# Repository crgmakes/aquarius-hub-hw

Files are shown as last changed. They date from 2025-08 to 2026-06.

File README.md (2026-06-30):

# Aquarius Hub Hardware

All the source files for the hub hardware.

# Software 

You will need [KiCad](https://kicad.org) to view and edit this design. Click [here](https://www.kicad.org/download/) to download.

You will also need all the associated libraries and models to drive the design if you want to make changes or view the 3D rendering:

https://github.com/crgmakes/kicad-library.git

Kicad MUST be configured properly to use all the files in this repo. Once you have Kicad installed, under Preferences->Configure Paths..., make the following entries:

1 - KICAD_USER_DIR -> set to the root location of where you placed the above repository.
2 - KICAD_USER_LIBRARY = ${KICAD_USER_DIR}/Library
3 - KICAD_USER_MODEL_DIR = ${KICAD_USER_LIBRARY}/models
4 - KICAD_USER_TEMPLATE_DIR	= ${KICAD_USER_LIBRARY}/templates	

Kicad will operate mostly normally if these are not set properly. You will notice an issue when you view the PCB in 3D mode.

***NOTE***: after makeing a release build in git, if your rendered 3D images are missing components, ensure the path to EVERY component model is set to ${KICAD_USER_MODEL_DIR}/<model name>.

Kicad sometimes replaces the variable with an expansion and that FAILS during the build process because the expanded variable is local and does not match the build environment.

---

THE DESIGN IS PROVIDED "AS IS" AND THE AUTHOR DISCLAIMS ALL WARRANTIES WITH REGARD TO THIS DESIGN INCLUDING ALL IMPLIED WARRANTIES OF MERCHANTABILITY AND FITNESS. IN NO EVENT SHALL THE AUTHOR BE LIABLE FOR ANY SPECIAL, DIRECT, INDIRECT, OR CONSEQUENTIAL DAMAGES OR ANY DAMAGES WHATSOEVER RESULTING FROM LOSS OF USE, DATA OR PROFITS, WHETHER IN AN ACTION OF CONTRACT, NEGLIGENCE OR OTHER TORTIOUS ACTION, ARISING OUT OF OR IN CONNECTION WITH THE USE OR PERFORMANCE OF THIS DESIGN.

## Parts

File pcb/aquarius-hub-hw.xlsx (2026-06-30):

Designator | Type | Value | Footprint | Populate | CPN | Manufacturer 1 | MPN 1 | Digikey | LCSC | Mouser
C1,C4,C5,C6,C7,C9 |  | 0.1uF | CRGM Passive:C_0603_1608Metric |  |  | Samsung | CL10B104KO8NNNC | 1276-1005-2-ND | C66501 | 187-CL10B104KO8NNNC
C2,C11,C12,C13 |  | 10uF | CRGM Passive:C_0603_1608Metric |  |  | Samsung | CL10A106MO8NQNC | 1276-1870-2-ND | C92487 | 187-CL10A106MO8NQNC
C3,C10,C14 |  | 1uF | CRGM Passive:C_0603_1608Metric |  |  | HRE | CL10B105KO8NNNC | 1276-1019-2-ND | C6119849 | 187-CL10B105KO8NNNC
C8 |  | 100uF | CRGM Passive:C_1206_3216Metric |  |  | Samsung | CL31A107MQHNNNE | 1276-1782-2-ND | C15008 | 187-CL31A107MQHNNNE
C17 |  | 220uF | CRGM Passive:CP_Elec_6.3x5.4 |  |  | ROQANG | RVT1A221M0605 | 3372-UE227M010HEHTATR-ND | C72494 | 80-EDH227M6R3A9GAA
D1 |  | WS2812B-2020 | LED_SMD:LED_WS2812B-2020_PLCC4_2.0x2.0mm |  |  | World Semi | WS2812C-2020-V1 |  | C5349954
D2 |  | D_Schottky | CRGM Passive:D_SOD-523 |  |  | Shikues | MSK4010 | 1727-5834-2-ND | C345958 | 771-PMEG3010EB115
D3,D20 |  | PESD5V5C1BL | CRGM Passive:DFN1006-2 |  |  | Nexperia | PESD5V5C1BLYL | 1727-PESD5V5C1BLYLTR-ND | C2827636 | 771-PESD5V5C1BLYL
D4,D5,D6,D7,D8,D9,D10,D11,D12,D13,D14,D15,D16,D17,D18,D19,D21,D22,D25,D26,D27,D28 |  | PESD3V3S1BL | CRGM Passive:DFN1006-2 |  |  | FUXINSEMI | LESD8D3.3CAT5G | 1727-PESD3V3S1BLYLTR-ND | C5563754 | 621-DESD3V3S1BL-7B
D23,D24 |  | Orange | CRGM Passive:LED_0603_1608Metric |  |  | XINGLIGHT | XL-1608UOC-06 | 5962-XL-1608UOC-06TR-ND | C965800 | 859-LTST-C190KFKT
J1 |  | ~ | CRGM Connector:XF2M-1415-1A |  |  | Omron | XF2M-1415-1A | OR755TR-ND | C397114 | 653-XF2M-1415-1A
J2 |  | USB_C_USB2.0_16P | CRGM Connector:GCT_USB4105-GF-A |  |  | GTC | USB4105-GF-A-060 | 2073-USB4105-GF-A-060TR-ND | C165948 | 640-USB4105-GF-A-060
J3,J11,J14 |  | ~ | CRGM Connector:JST_SH_BM03B-SRSS-TB_1x03-1MP_P1.00mm_Vertical |  |  | JST | BM03B-SRSS-TB | 455-BM03B-SRSS-TBTR-ND | C2904985 | 306-BM03BSRSSTBTLFSN
J4,J5,J7 |  | ~ | CRGM Connector:JST_SH_BM06B-SRSS-TB_1x06-1MP_P1.00mm_Vertical |  |  | JST | BM06B-SRSS-TBT(LF)(SN) | 455-BM06B-SRSS-TBTR-ND | C2845374 | 306-BM06BSRSSTBTLFSN
J6,J10 |  | ~ | CRGM Connector:JST_SH_BM08B-SRSS-TB_1x08-1MP_P1.00mm_Vertical |  |  | JST | BM08B-SRSS-TB(LF)(SN) | 455-BM08B-SRSS-TBTR-ND | C2845376 | 306-BM08BSRSSTBLFSN
J8,J9,J12 |  | ~ | CRGM Connector:JST_SH_BM04B-SRSS-TB_1x04-1MP_P1.00mm_Vertical |  |  | JST | BM04B-SRSS-TBT(LF)(SN) | 455-BM04B-SRSS-TBTR-ND | C2919601 | 306-BM04BSRSSTBTLFSN
LS1 |  | FUET-5020 | CRG Makes:FUET-5025 |  |  | Fuet | FUET-5020 | 102-CMT-0502-75-SMT-TR-ND | C391029 | 490-CMT-0502-75SMTTR
Q1 |  | MMBT2222A | CRGM Passive:SOT-523 |  |  | Diodes Incorporated | MMBT2222AT-7-F | MMBT2222AT-FDITR-ND | C151009 | 621-MMBT2222AT-F
R1,R2,R15 |  | 4.7K | CRGM Passive:R_0603_1608Metric |  |  | FOJAN | FRC0603J472 TS | CR0603-JW-472ELFTR-ND | C2907166 | 652-CR0603-JW-472ELF
R3,R4,R5,R6,R7,R8,R9,R13,R14 |  | 10K | CRGM Passive:R_0603_1608Metric |  |  | FOJAN | FRC0603J103TS | CR0603-JW-103ELFTR-ND | C2930027 | 652-CR0603-JW-103ELF
R10,R11 |  | 5.1K | CRGM Passive:R_0603_1608Metric |  |  | FOJAN | FRC0603J512 TS | 118-CR0603-JW-512ELFTR-ND | C2907114 | 652-CR0603JW-512ELF
R12,R16 |  | 1K | CRGM Passive:R_0603_1608Metric |  |  | FOJAN | FRC0603J102 TS | CR0603-JW-102ELFTR-ND | C2907113 | 652-CR0603-JW-102ELF
SW1,SW2 |  | SKRPABE010 | CRGM Switches:SMD-4P-4.2x3.2mm |  |  | ALPS Electric | SKRPABE010 | 4809-SKRPABE010TR-ND | C115360 | 688-SKRPAB
U1 |  | ESP32-S3-WROOM-1-N16R2 | CRG Makes:ESP32-S3-WROOM-1-N16R2 |  |  | Espressif | ESP32-S3-WROOM-1-N16R2 | 5407-ESP32-S3-WROOM-1-N16R2-ND | C2913205 | 356-ESP32-S3WRM1N16R2
U2 |  | LM66200DRLR | CRGM Power:SOTFL50P160X60-8N |  |  | Texas Instruments | LM66200DRLR | 296-LM66200DRLRTR-ND | C3235556 | 595-LM66200DRLR
U3 |  | USBLC6-2P6 | CRGM Passive:SOT-666 |  |  | TECH PUBLIC | USBLC6-2P6 | 497-5026-2-ND | C2827693 | 511-USBLC6-2P6
U4 |  | MCP23017T-E/ML | CRG Makes:QFN-28-1EP_6x6mm_P0.65mm_EP4.25x4.25mm |  |  | Microchip Tech | MCP23017T-E/ML | MCP23017-E/ML-ND | C629439 | 579-MCP23017-E/ML
U7 |  | AZ1084-3.3 | CRGM Power:TO-252-2 |  |  | Diodes Incorporated | AZ1084CD-3.3TRG1 | AZ1084CD-3.3TRG1DITR-ND | C151391 | 621-AZ1084CD-3.3TRG1

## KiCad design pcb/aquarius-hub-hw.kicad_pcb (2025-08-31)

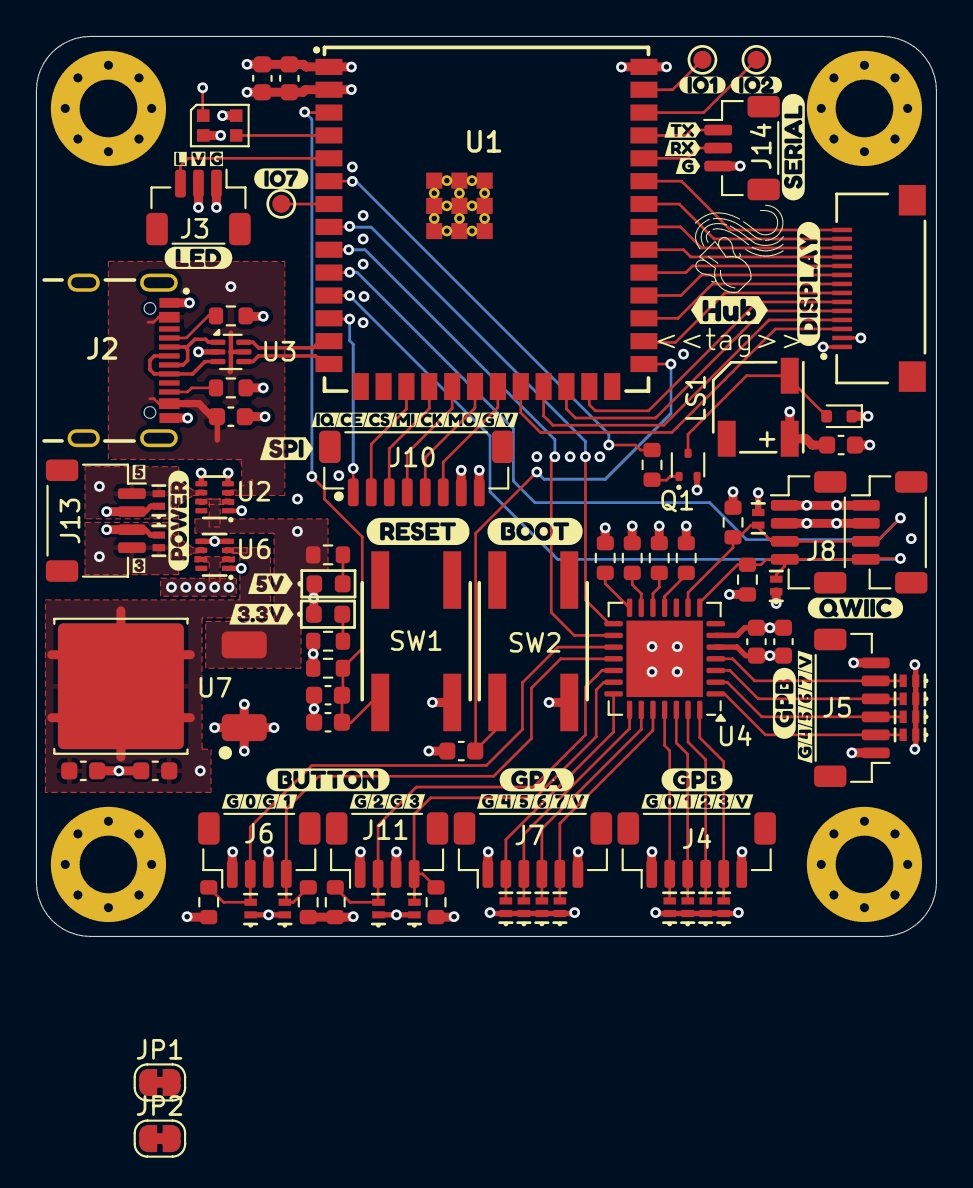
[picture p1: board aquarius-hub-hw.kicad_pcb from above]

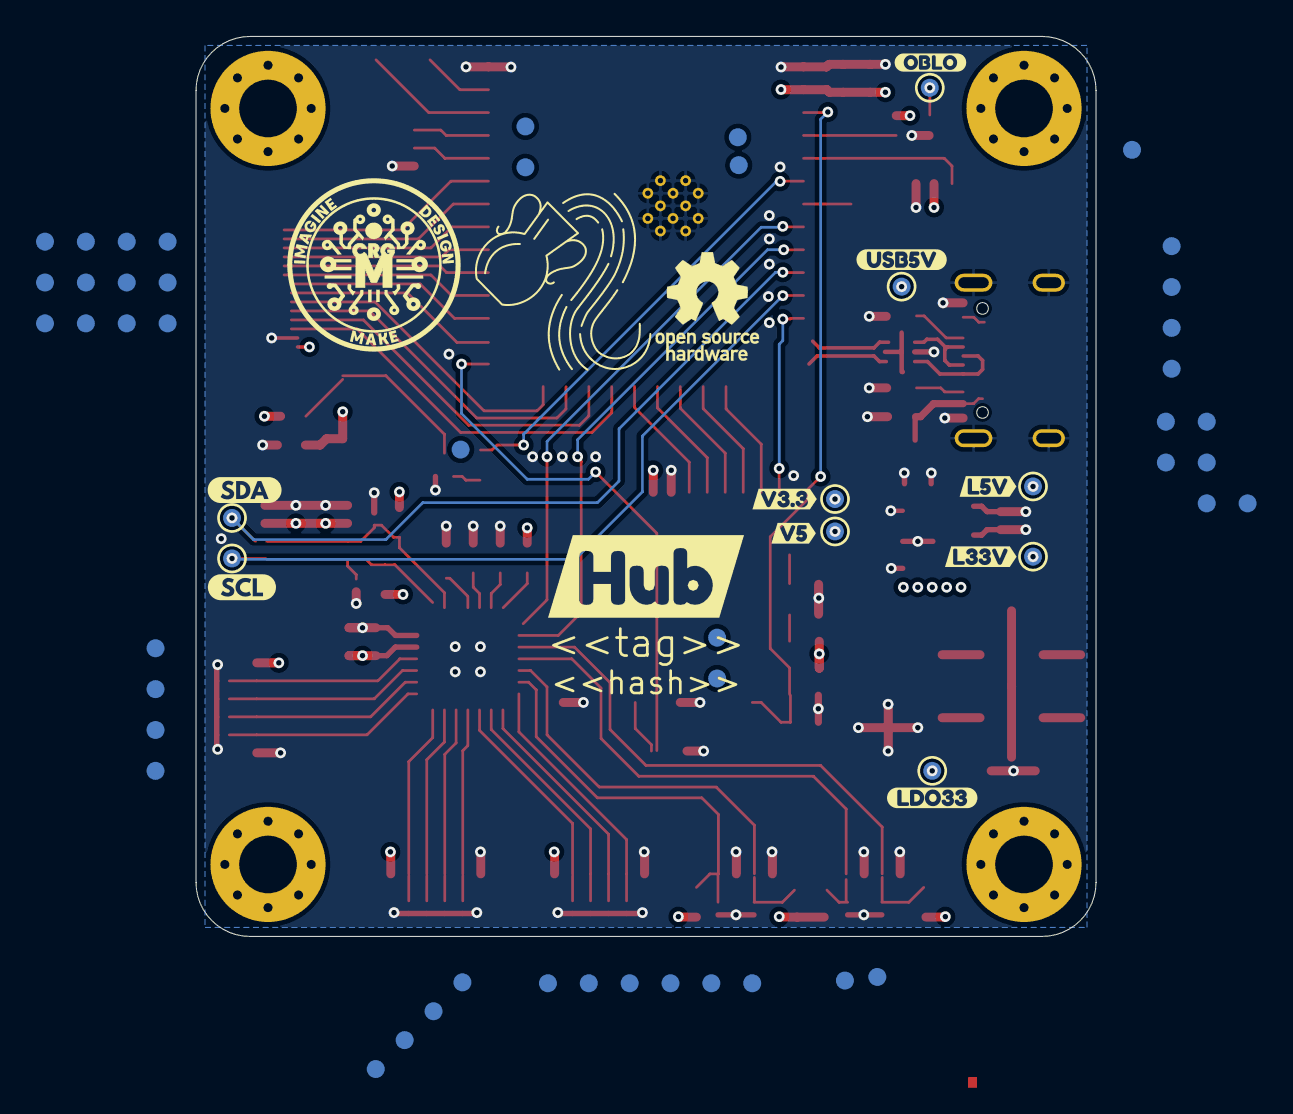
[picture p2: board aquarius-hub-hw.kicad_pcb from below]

Board: 4 copper layers, 50.0 x 50.0 mm, 212 parts (68 on the bottom side), 72 nets.

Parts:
C1, C4, C5, C6, C9: 0.1uF; C_0603_1608Metric
C2, C11, C12: 10uF; C_0603_1608Metric
C3, C10, C14: 1uF; C_0603_1608Metric
D1: WS2812B-2020; LED_WS2812B-2020_PLCC4_2.0x2.0mm
D2: D_Schottky; D_SOD-523
D4, D5, D6, D7, D8, D9, D10, D11, D12, D13, D14, D15, D16, D17, D18, D19, D21, D22, D25: PESD3V3S1BL; DFN1006-2
D20: PESD5V5C1BL; DFN1006-2
D23, D24: Orange; LED_0603_1608Metric
H1, H2, H3, H4: MountingHole_3.2mm_M3_Pad_Via
J1: XF2M-1415-1A
J2: USB_C_USB2.0_16P; GCT_USB4105-GF-A
J3, J14: BM03B-SRSS-TB; JST_SH_BM03B-SRSS-TB_1x03-1MP_P1.00mm_Vertical
J4, J5, J7: BM06B-SRSS-TB; JST_SH_BM06B-SRSS-TB_1x06-1MP_P1.00mm_Vertical
J6, J8, J9, J11: BM04B-SRSS-TB; JST_SH_BM04B-SRSS-TB_1x04-1MP_P1.00mm_Vertical
J10: BM08B-SRSS-TB; JST_SH_BM08B-SRSS-TB_1x08-1MP_P1.00mm_Vertical
J13: SM04B-SRSS-TB; JST_SH_SM04B-SRSS-TB_1x04-1MP_P1.00mm_Horizontal
JP1, JP2: SolderJumper-2_P1.3mm_Bridged_RoundedPad1.0x1.5mm
LOGO1: CRGM Logo 5mm
LOGO2: Aquarius Logo 10mm
LOGO3: OSHW-Logo_5.7x6mm_SilkScreen
LOGO4: Aquarius Logo 5mm
LS1: FUET-5025
Q1: MMBT2222A; SOT-523
R1, R2, R15: 4.7K; R_0603_1608Metric
R3, R4, R5, R6, R7, R8, R9, R13, R14: 10K; R_0603_1608Metric
R10, R11: 5.1K; R_0603_1608Metric
R12, R16: 1K; R_0603_1608Metric
SW1, SW2: EVQ-Q2B02W
TP1, TP2, TP3, TP4, TP5, TP6, TP7, TP8, TP9, TP10, TP11, TP12, TP13, TP14, TP15, TP16, TP17, TP18, TP19, TP20, TP21, TP22, TP23, TP24, TP25, TP26, TP27, TP28, TP29, TP30, TP31, TP32, TP33, TP34, TP35, TP36, TP37, TP38, TP39, TP40, TP41, TP42, TP43, TP44, TP45, TP46, TP47, TP48, TP49, TP50, TP51, TP52, TP53, TP54, TP55, TP56, TP57, TP58: TestPoint_Pad_D1.0mm
U1: ESP32-S3-WROOM-1-N8R2
U2, U6: LM66200DRLR; SOTFL50P160X60-8N
U3: USBLC6-2P6; SOT-666
U4: MCP23017T-E/ML; QFN-28-1EP_6x6mm_P0.65mm_EP4.25x4.25mm
U7: AZ1084-3.3; TO-252-2
kibuzzard-67B9F9C2: G***; kibuzzard-67B9F9C2
kibuzzard-67B9F9CD: G***; kibuzzard-67B9F9CD
kibuzzard-680D06A5: G***; kibuzzard-680D06A5
kibuzzard-680D069E: G***; kibuzzard-680D069E
kibuzzard-680D0262: G***; kibuzzard-680D0262
kibuzzard-683B54B0: G***; kibuzzard-683B54B0
kibuzzard-683B594D: G***; kibuzzard-683B594D
kibuzzard-683B5370: G***; kibuzzard-683B5370
kibuzzard-683B5376: G***; kibuzzard-683B5376
kibuzzard-683C500B: G***; kibuzzard-683C500B
kibuzzard-683C5017: G***; kibuzzard-683C5017
kibuzzard-689E525E: G***; kibuzzard-689E525E
kibuzzard-689E5275: G***; kibuzzard-689E5275
kibuzzard-6812E3A0: G***; kibuzzard-6812E3A0
kibuzzard-6812E3AD: G***; kibuzzard-6812E3AD
kibuzzard-6812E3BB: G***; kibuzzard-6812E3BB
kibuzzard-6812E3C5: G***; kibuzzard-6812E3C5
kibuzzard-6812E37E: G***; kibuzzard-6812E37E
kibuzzard-6812E420: G***; kibuzzard-6812E420
kibuzzard-68153CC4, kibuzzard-68153CC4#2, kibuzzard-68153CC4#3: G***; kibuzzard-68153CC4
kibuzzard-68153CC9: G***; kibuzzard-68153CC9
kibuzzard-68153CCE: G***; kibuzzard-68153CCE
kibuzzard-68153CDD: G***; kibuzzard-68153CDD
kibuzzard-68153CE4: G***; kibuzzard-68153CE4
kibuzzard-68153CEB: G***; kibuzzard-68153CEB
kibuzzard-68153CEF: G***; kibuzzard-68153CEF
kibuzzard-68194F3F: G***; kibuzzard-68194F3F
kibuzzard-68194F50: G***; kibuzzard-68194F50
kibuzzard-68366CAF: G***; kibuzzard-68366CAF
kibuzzard-68574A7C: G***; kibuzzard-68574A7C
kibuzzard-68574A8F: G***; kibuzzard-68574A8F
kibuzzard-68574A9F: G***; kibuzzard-68574A9F
kibuzzard-68574AC2: G***; kibuzzard-68574AC2
kibuzzard-68574AD3: G***; kibuzzard-68574AD3
kibuzzard-68574B95: G***; kibuzzard-68574B95
kibuzzard-68574D7F: G***; kibuzzard-68574D7F
kibuzzard-68574D8A: G***; kibuzzard-68574D8A
kibuzzard-68574D75: G***; kibuzzard-68574D75
kibuzzard-68574D94: G***; kibuzzard-68574D94
kibuzzard-681420CD: G***; kibuzzard-681420CD
kibuzzard-681420D1: G***; kibuzzard-681420D1
kibuzzard-681420D5: G***; kibuzzard-681420D5
kibuzzard-681420DA, kibuzzard-681420DA#2: G***; kibuzzard-681420DA
kibuzzard-681420E9: G***; kibuzzard-681420E9
kibuzzard-681420F3: G***; kibuzzard-681420F3
kibuzzard-681421A1: G***; kibuzzard-681421A1
kibuzzard-681421A9: G***; kibuzzard-681421A9
kibuzzard-683921F2: G***; kibuzzard-683921F2
kibuzzard-6810346D: G***; kibuzzard-6810346D
kibuzzard-6810349E: G***; kibuzzard-6810349E
kibuzzard-6814204F, kibuzzard-6814204F#2: G***; kibuzzard-6814204F
kibuzzard-6814212B: G***; kibuzzard-6814212B
kibuzzard-6815408B: G***; kibuzzard-6815408B
kibuzzard-6857318D: G***; kibuzzard-6857318D
kibuzzard-68142030, kibuzzard-68142030#2: G***; kibuzzard-68142030
kibuzzard-68142039, kibuzzard-68142039#2: G***; kibuzzard-68142039
kibuzzard-68142043, kibuzzard-68142043#2: G***; kibuzzard-68142043
kibuzzard-68142110: G***; kibuzzard-68142110
kibuzzard-68142199: G***; kibuzzard-68142199
kibuzzard-68154095, kibuzzard-68154095#2, kibuzzard-68154095#3: G***; kibuzzard-68154095
kibuzzard-68392226: G***; kibuzzard-68392226

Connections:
+3.3V: C1.1, C2.1, C9.1, C10.1, C14.1, D1.4 (VDD), D2.1 (K), J1.1, J3.2, J4.6, J5.6, J7.6, J8.2, J9.2, J10.8, LS1.2 (+), R1.1, R2.1, R3.1, R4.1, R5.1, R9.1, R13.1, R14.1, R16.1, TP8.1, U1.2 (3V3), U4.5 (VDD), U6.2 (VOUT1), U6.7 (VOUT2)
+5V: R15.1, TP12.1, U2.2 (VOUT1), U2.7 (VOUT2), U7.3 (VI)
/Interfaces/BUZZ_GND: D2.2 (A), LS1.3 (-), Q1.3 (C)
/PIO/A0: R6.1, U4.11 (A0)
/PIO/A1: R7.1, U4.12 (A1)
/PIO/A2: R8.1, U4.13 (A2)
/PIO/BTN0: D12.2 (K2), J6.2, R14.2, TP51.1, U4.17 (GPA0)
/PIO/BTN1: D13.2 (K2), J6.4, R13.2, TP52.1, U4.18 (GPA1)
/PIO/BTN2: D14.2 (K2), J11.2, R5.2, TP53.1, U4.19 (GPA2)
/PIO/BTN3: D15.2 (K2), J11.4, R4.2, TP54.1, U4.20 (GPA3)
/PIO/GPA4: D16.2 (K2), J7.2, TP55.1, U4.21 (GPA4)
/PIO/GPA5: D17.2 (K2), J7.3, TP56.1, U4.22 (GPA5)
/PIO/GPA6: D18.2 (K2), J7.4, TP57.1, U4.23 (GPA6)
/PIO/GPA7: D19.2 (K2), J7.5, TP58.1, U4.24 (GPA7)
/PIO/GPB0: D4.2 (K2), J4.2, TP43.1, U4.25 (GPB0)
/PIO/GPB1: D5.2 (K2), J4.3, TP44.1, U4.26 (GPB1)
/PIO/GPB2: D6.2 (K2), J4.4, TP45.1, U4.27 (GPB2)
/PIO/GPB3: D7.2 (K2), J4.5, TP46.1, U4.28 (GPB3)
/PIO/GPB4: D8.2 (K2), J5.2, TP47.1, U4.1 (GPB4)
/PIO/GPB5: D9.2 (K2), J5.3, TP48.1, U4.2 (GPB5)
/PIO/GPB6: D10.2 (K2), J5.4, TP49.1, U4.3 (GPB6)
/PIO/GPB7: D11.2 (K2), J5.5, TP50.1, U4.4 (GPB7)
/PIO/PIO_RESET: R9.2, U4.14 (~RESET)
/Power/CC1: J2.A5 (CC1), R11.1
/Power/CC2: J2.B5 (CC2), R10.1
/Power/V3.3LED: D24.2 (A), R16.2
/Power/V5LED: D23.2 (A), R15.2
BOOT: C5.1, SW2.B1 (B), TP41.1, U1.27 (IO0)
BUZZER: R12.1, TP42.1, U1.6 (IO6)
D_N: TP25.1, U1.13 (USB_D-), U3.6 (I/O1)
D_P: TP26.1, U1.14 (USB_D+), U3.4 (I/O2)
EN: C3.1, C4.1, R3.2, SW1.B1 (B), TP40.1, U1.3 (EN)
GND: C1.2, C2.2, C3.2, C4.2, C5.2, C6.2, C9.2, C10.2, C11.2, C12.2, C14.2, D1.2 (VSS), D4.1 (K1), D5.1 (K1), D6.1 (K1), D7.1 (K1), D8.1 (K1), D9.1 (K1), D10.1 (K1), D11.1 (K1), D12.1 (K1), D13.1 (K1), D14.1 (K1), D15.1 (K1), D16.1 (K1), D17.1 (K1), D18.1 (K1), D19.1 (K1), D20.1 (K1), D21.1 (K1), D22.1 (K1), D25.1 (K1), J1.2, J2.A1B12 (GND), J2.B1A12 (GND), J2.S1 (SHIELD), J3.1, J4.1, J5.1, J6.1, J6.3, J7.1, J8.1, J9.1, J10.7, J11.1, J11.3, J13.2 (GND), J13.3 (GND), J14.3, JP1.1 (A), JP2.1 (A), Q1.2 (E), R6.2, R7.2, R8.2, R10.2, R11.2, SW1.A1 (A), SW2.A1 (A), U1.1 (GND), U1.40 (GND), U1.41 (GND), U2.1 (GND1), U2.4 (~ON), U2.5 (GND2), U3.2 (GND), U4.6 (VSS), U4.29 (EP), U6.1 (GND1), U6.4 (~ON), U6.5 (GND2), U7.1 (GND)
I2C_SCL: D21.2 (K2), J8.4, J9.4, R2.2, TP2.1, U1.11 (IO18), U4.8 (SCK)
I2C_SDA: D22.2 (K2), J8.3, J9.3, R1.2, TP1.1, U1.10 (IO17), U4.9 (SDA)
LCD_BL: J1.8, TP18.1, U1.29 (IO36)
LCD_CS: J1.3, TP13.1, U1.22 (IO14)
LCD_DC: J1.5, TP15.1, U1.24 (IO47)
LCD_RS: J1.4, TP14.1, U1.23 (IO21)
LCD_SCK: J1.7, TP17.1, U1.28 (IO35)
LCD_SDI: J1.6, TP16.1, U1.25 (IO48)
LCD_SDO: J1.9, TP19.1, U1.30 (IO37)
LDO_V33: C11.1, C12.1, TP9.1, U6.3 (VIN1), U7.2 (VO)
LEDS: J3.3, U1.5 (IO5)
LINE_5V: D20.2 (K2), J13.1 (V5), TP10.1, U2.6 (VIN2)
LINE_V33: D25.2 (K2), J13.4 (V3.3), TP11.1, U6.6 (VIN2)
unnamed: D23.1 (K), JP1.2 (B)
unnamed: D24.1 (K), JP2.2 (B)
unnamed: Q1.1 (B), R12.2
unnamed: TP5.1, U1.39 (IO1)
unnamed: TP6.1, U1.38 (IO2)
unnamed: TP7.1, U1.7 (IO7)
OBL: D1.3 (DIN), TP39.1, U1.4 (IO4)
OBL_OUT: D1.1 (DOUT), TP3.1
PIO_INTA: TP37.1, U1.8 (IO15), U4.15 (INTB)
PIO_INTB: TP38.1, U1.9 (IO16), U4.16 (INTA)
RX: J14.2, TP30.1, U1.36 (RXD0)
SD_CS: J1.14, TP24.1, U1.35 (IO42)
SPI_CE0: J10.2, TP32.1, U1.17 (IO9)
SPI_CLK: J10.5, TP35.1, U1.20 (IO12)
SPI_CS0: J10.3, TP33.1, U1.18 (IO10)
SPI_IRQ0: J10.1, TP31.1, U1.12 (IO8)
SPI_MISO: J10.4, TP34.1, U1.19 (IO11)
SPI_MOSI: J10.6, TP36.1, U1.21 (IO13)
TX: J14.1, TP29.1, U1.37 (TXD0)
T_INT: J1.13, TP23.1, U1.34 (IO41)
T_RESET: J1.11, TP21.1, U1.32 (IO39)
T_SCL: J1.10, TP20.1, U1.31 (IO38)
T_SDA: J1.12, TP22.1, U1.33 (IO40)
USB_5V: C6.1, J2.A4B9 (VBUS), J2.B4A9 (VBUS), TP4.1, U2.3 (VIN1), U3.5 (VBUS)
USB_D_N: J2.A7 (D-), J2.B7 (D-), TP27.1, U3.1 (I/O1)
USB_D_P: J2.A6 (D+), J2.B6 (D+), TP28.1, U3.3 (I/O2)

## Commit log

2025-04-29 Major updates to IO and board size
    some issue with display of properties in schematic view.
    [Node copy.kicad_pcb, Node.kicad_pcb, io.kicad_sch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]
2025-04-30 Added buzzer
    [Node.kicad_pcb, mcu.kicad_sch, peripherals.kicad_sch]
2025-05-01 Changed SPI to 8 pin connector
    [Node.kicad_pcb, mcu.kicad_sch, peripherals.kicad_sch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]
2025-05-02 Added additional labels; minor clean up.
    [Node.kicad_pcb, peripherals.kicad_sch, pio.kicad_sch]
2025-05-05 added open hw; changed test points; added pulls on buttons
    change buttons to be 2 connectors with pull ups.
    [Node.kicad_pcb, mcu.kicad_sch, pio.kicad_sch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]
2025-05-05 added 1x2 panel
    [aq-hw-panel-sample.kicad_pcb, node-panel-1x2.kicad_pcb]
2025-05-08 Change panel to be 1x1
    Changed connectors be vertical rather than horizontal.
    Updated TVS diodes to DFN1006 rather than SMF
    [Node.kicad_pcb, Node.kicad_sch, mcu.kicad_sch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]
2025-06-01 Major overhaul of IO
    Added GPIO module
    Added SPI interface
    Added serial interface
    Added power selection
    Added power LEDs
    Changed v3.3 LDO
    [Node copy.kicad_pcb, Node.kicad_pcb, Node.kicad_sch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]
2025-06-01 Updated raytracing images on main page
    [Node.kicad_pcb, aq-hw-panel-sample.kicad_pcb]
2025-06-02 Fixed MPN mismatches and other fields
    [Node.kicad_pcb, mcu.kicad_sch, peripherals.kicad_sch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]
2025-06-02 Filleted PCB corners
    [Node.kicad_pcb]
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2025-06-03 Removed duplicative ESB on USB
    Updated descriptions for consistency
    [Node.kicad_pcb, mcu.kicad_sch, peripherals.kicad_sch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]
2025-06-07 Fixed cap values on reset button
    Fixed all part numbers and extended parameters.
    [Node.kicad_pcb, mcu.kicad_sch, peripherals.kicad_sch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]
2025-06-09 Rationalized attributes; excluded some footprints from BOM
    [Node.kicad_pcb, mcu.kicad_sch, power.kicad_sch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]
2025-06-21 Continued rationalizing parts
    [Node.kicad_pcb]
2025-06-21 Updated dimensions; updated mounting hole footprint
    [Node.kicad_pcb, mcu.kicad_sch]
2025-06-21 Adjusted part values
    Fixed LCSC footprints for connectors
    Moved EN 5% instead of 1%
    Moved I2C pull ups to 4.7K
    [Node.kicad_pcb, mcu.kicad_sch, peripherals.kicad_sch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]
2025-06-22 Cleaned up fab layer. Minor tweaks. Updated renders.
    [Node.kicad_pcb, peripherals.kicad_sch, pio.kicad_sch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]
2025-06-23 closed #3 and #1
    Fixed resistors and values
    Widened panel
    [Node.kicad_pcb, mcu.kicad_sch, peripherals.kicad_sch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]
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2025-06-24 updated ci script to include date of release and cash in schematic
    [mcu.kicad_sch, peripherals.kicad_sch, pio.kicad_sch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]
2025-06-24 added all schematics to tagging; remove unused files
    [io.kicad_sch, sensors.kicad_sch]
2025-06-26 Updated frame template
    [Node.kicad_pcb, mcu.kicad_sch, peripherals.kicad_sch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]
2025-06-26 Added PCB requirements to requirements sheet; adjusted user drawing layer a little
    [Node.kicad_pcb, requirements.kicad_sch]
2025-06-26 Fixed serial model; fixed CI script
    [Node.kicad_pcb]
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2025-06-27 Updated worksheet template and logo
    [Node.kicad_pcb, requirements.kicad_sch]
2025-06-27 fixed case of release file name.
2025-06-28 Fixed footprint for Buzzer, XFC, USB ESD, and Power Switcher
    [Node.kicad_pcb, mcu.kicad_sch, peripherals.kicad_sch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]
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2025-06-28 Updated PCB for DFM
    [Node.kicad_pcb]
2025-06-28 Fixed missing packages
    [Node.kicad_pcb]
2025-06-28 Fixed module path for buzzer
    [Node.kicad_pcb]
2025-06-29 Minor trace clean up; set stack up colors.
    [Node.kicad_pcb]
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2025-07-13 Added test points. Fixed license file.
    [Node.kicad_pcb, mcu.kicad_sch, peripherals.kicad_sch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]
2025-07-24 Updated license and minor schematic changes
    [pio.kicad_sch]
2025-08-11 Minor updates to ESP part number/footprint
    [mcu.kicad_sch]
2025-08-12 Changed name to hub
    [Hub.kicad_pcb]
2025-08-12 Change name in schematic
    [mcu.kicad_sch, peripherals.kicad_sch, pio.kicad_sch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]
2025-08-14 Changed graphics to Hub from Node
    [Hub.kicad_pcb]
2025-08-23 Renamed files; update with more test points
    [Hub.kicad_pcb, aquarius-hub-hw.kicad_pcb, aquarius-hub-hw.kicad_sch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]
2025-08-23 Renamed peripherals to interfaces; added test points; added led jumper
    [aquarius-hub-hw.kicad_pcb, interfaces.kicad_sch, mcu.kicad_sch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]
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2025-09-02 Sync symbols and footprints
    Transitioned to CRGM footprints
    Added dimensions
    Fixed some spacing
    Adjusted properties
    [interfaces.kicad_sch, mcu.kicad_sch, pio.kicad_sch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]
2025-09-06 Clean up and consistency
    Moved buzzer to MCU
    Fixed model directory
    Set font size
    Set outline size
    Upscaled Roxy ❤️
    [interfaces.kicad_sch, mcu.kicad_sch, pio.kicad_sch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]
2025-09-08 Updated part attributes for consistency.
    Updated requirements section to be more accurate.
    [mcu.kicad_sch, pio.kicad_sch, power.kicad_sch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]
2025-09-09 fixed LCSC part numbers
    [interfaces.kicad_sch, pio.kicad_sch]
2025-10-23 Switched to internal and external I2C bus
    Updated renders
    Updated description of QWICC connectors
    Added test points for INT I2C
    [interfaces.kicad_sch, mcu.kicad_sch, pio.kicad_sch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]
2025-10-27 Rework to add power connector
    Simplified GPIO connectors to make sure for power.
    [interfaces.kicad_sch, mcu.kicad_sch, pio.kicad_sch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]
2025-10-28 Moved connectors
    Moved I2C to edge
    Rearranged all GPIO
    Re-routed as necessary
    (I don't like the button connector layout -- like the old way more)
    [mcu.kicad_sch, pio.kicad_sch, power.kicad_sch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]
2025-10-29 Fixed GPIO resistor annoyance
    Better ground now
    Stitching vias all around
    [mcu.kicad_sch]
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2025-11-04 renamed pio to peripheral
    [peripherals.kicad_sch]
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2025-11-25 Added bulk caps to v3.3 for better smoothing
    [power.kicad_sch]
2025-12-18 Moved to vertical connectors
    [interfaces.kicad_sch, mcu.kicad_sch, peripherals.kicad_sch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]
2025-12-19 Changed button connector to ground every other
    [peripherals.kicad_sch]
2025-12-22 Added 220uF cap on Power
    Rearranged accordingly
    Can be upgraded to 470uF if required.
    [power.kicad_sch]
2025-12-27 Updated cooper pour
    Updated footprint for TO-252-3
    Adjusted pours
    Adjusted spacing
    Change buzzer and LED names on schematic
    [mcu.kicad_sch]
2025-12-29 Fixed power input
    Removed 3.3v selection
    Removed unnecessary caps
    Rerouted as necessary
    Fixed silkscreen
    [power.kicad_sch, requirements.kicad_sch]
2025-12-29 Updated renders
    Minor clean up.
    [power.kicad_sch]
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2026-02-24 Minor silkscreen changes.
    Updated 2222 footprint
    Ready for next release
    [interfaces.kicad_sch, mcu.kicad_sch, peripherals.kicad_sch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]
2026-02-25 Temoved duplicative test points
    Cleaned up routing and silkscreen.
    Updated mounting holes and tied to ground.
    [interfaces.kicad_sch, requirements.kicad_sch]
2026-02-27 Added TVS to LED and Serial
    Minor silkscreen updates
    [interfaces.kicad_sch]
2026-03-06 Fixed part placement and missing model
    Both display and 3.3 regulator were in the wrong place after updating from library!
    LED was missing model
    Minor silkscreen changes
    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
    [interfaces.kicad_sch, mcu.kicad_sch, peripherals.kicad_sch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]
2026-03-06 Fixed silkscreen on pad issue
2026-03-06 Updated models and values
    Updated ESP value to N16R2
    Cleaned up test points for LCD
    Changed to N16R2 model
    [mcu.kicad_sch]
2026-03-06 Fixed value property for MCU
    removed filters from ESP32 symbol
    [mcu.kicad_sch]
2026-03-12 Updated foot prints and symbols
    [interfaces.kicad_sch, mcu.kicad_sch, peripherals.kicad_sch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]
2026-03-12 Updated footprints and rotations
    [interfaces.kicad_sch, mcu.kicad_sch, power.kicad_sch]
2026-03-12 Fixed LCSC part # for power connector
    [mcu.kicad_sch, peripherals.kicad_sch, power.kicad_sch]
2026-03-13 Fixed part numbers
    Fixed 3 pin JST LCSC Part Number
    Fixed MPN for JST 3 pin
    Changed Hub to Node on top silkscreen
    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
    [interfaces.kicad_sch, power.kicad_sch]
2026-05-28 Added analog port
    re-routed
    resized the pretty princess
    [interfaces.kicad_sch, mcu.kicad_sch, power.kicad_sch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]
